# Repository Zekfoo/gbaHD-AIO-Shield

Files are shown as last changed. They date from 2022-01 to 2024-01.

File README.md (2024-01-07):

# gbaHD AIO Shield



This is a Spartan Edge Accelerator shield which implements all the hardware connections needed for zwenergy's [gbaHD](https://github.com/zwenergy/gbaHD), no wires required! The PCB incorporates the GBA motherboard, Arduino Nano, and SNES controller port used in a typical gbaHD installation, and interfaces directly with the Spartan Edge Accelerator board via pin header connections. 



## Disclaimer

Assembly of this PCB requires donor parts from a Game Boy Advance motherboard, and therefore also requires advanced soldering skills. Do not attempt this project unless you are comfortable and confident in your ability to desolder and solder both surface-mount and through-hole components, otherwise you risk irreparable damage to your original console and to this PCB. I claim no responsibility and accept no blame for any failed attempts.

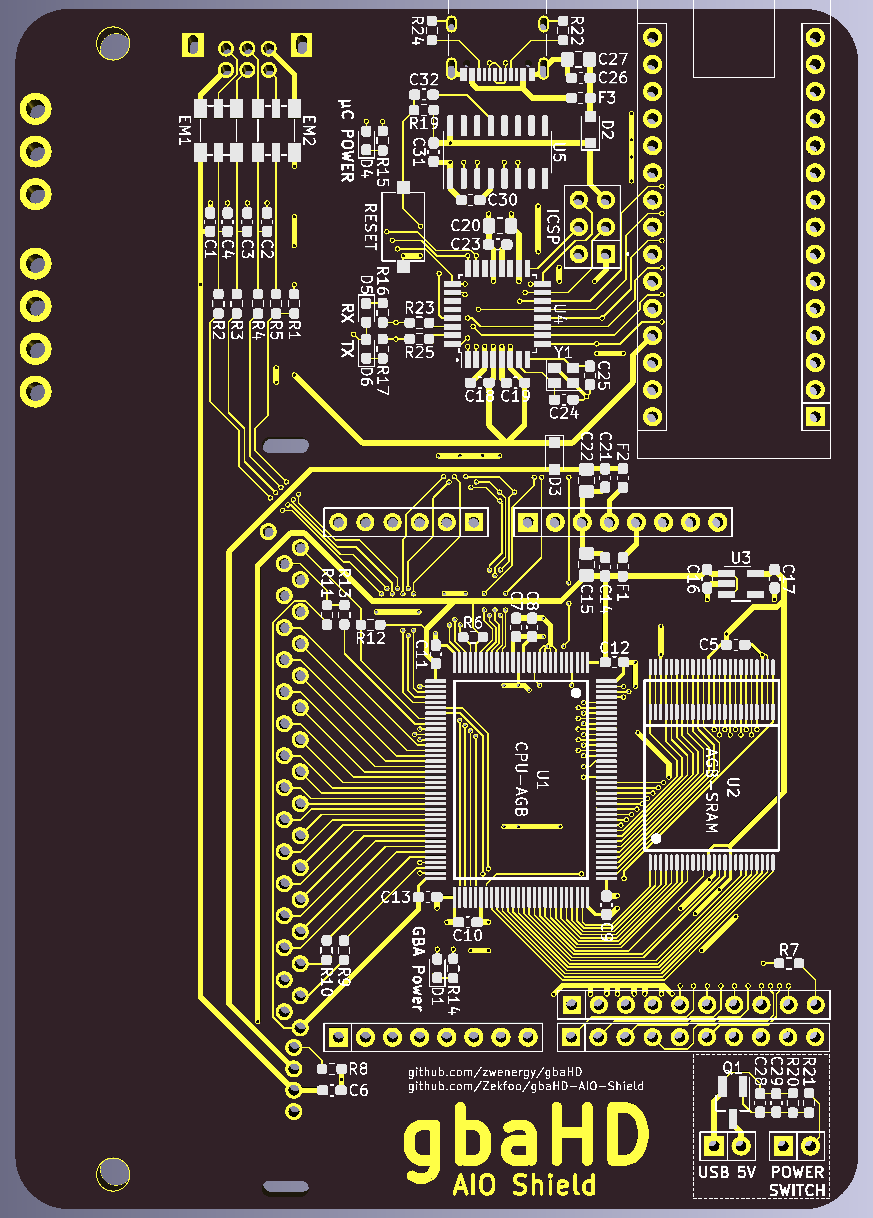
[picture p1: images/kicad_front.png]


## Ordering the board

**READ THE DISCLAIMER SECTION ABOVE BEFORE CONTINUING**

The PCB can be ordered via the following links:

**[PCBWay](https://www.pcbway.com/project/shareproject/gbaHD_AIO_Shield_8eb5e84a.html)** (Full disclosure - this link gives me a small commission from each order - if you're new to PCBWay, feel free to use my [referral link](https://www.pcbway.com/setinvite.aspx?inviteid=422136) to sign up and get $5 off your order)

**[OSHPark](https://oshpark.com/shared_projects/6wbIivMl)**

Or feel free to order from your preferred PCB fab using the gerbers on this repo.

Board thickness of 1.2mm or thinner is recommended. 1.6mm will work, but soldering of some of the through-hole components may be more difficult.

## Bill of materials

There are a couple *optional* features on this PCB to keep in mind before ordering your parts:

**Choice between an onboard ATmega328P or an external Arduino Nano**

The onboard Arduino offers a cleaner look for the assembled PCB, but since ATmega chips are becoming prohibitively expensive during this  chip shortage, there is also support for plugging in your own Arduino Nano via pin headers. *These options are mutually-exclusive, pick one.*

**Master power switch**

This may be useful for consolizer-style installations that use an enclosure, such that a toggle switch can be mounted to the case to switch power to the entire assembly while leaving the USB-C power supply plugged in. This is completely optional, since the power can be switched off using the Spartan Edge Accelerator's own switch or by unplugging the power supply.

The BOM below is separated between donor parts, required parts, and parts for optional features. Read carefully since the optional features may require components that are also listed in earlier sections.

Please source your own passive components, only values and footprints are listed for these.

|  | Reference(s) | Count | Description | Part Number | Comments | Purchase Link |
|---|---|---|---|---|---|---|
| **From donor GBA** | U1 | 1 | AGB CPU | - | - | - |
|  | U2 | 1 | AGB SRAM | - | - | - |
|  | P1 | 1 | Link port | - | - | - |
|  | P2 | 1 | Cart connector | - | - | - |
|  | EM1, EM2 | 2 | Common-mode choke | ACM4532-102-3P | - | - |
|  |  |  |  |  |  |  |
| **Required** | C1, C5, C6, C7, C8, C9, C10, C11, C12, C13, C14, C16, C17, C21 | 14 | 0.1uF 0603 | - | - | - |
|  | C2, C3, C4 | 3 | 100pF 0603 | - | - | - |
|  | C15, C22 | 2 | 10uF 0805 | - | - | - |
|  | D1, D4 | 2 | Green LED 0603 | LTST-C191KGKT | Or generic | https://lcsc.com/product-detail/Light-Emitting-Diodes-LED_Lite-On-LTST-C191KGKT_C125098.html |
|  | D3 | 1 | Schottky diode | B5817WS | - | https://lcsc.com/product-detail/Schottky-Barrier-Diodes-SBD_Yangzhou-Yangjie-Elec-Tech-B5817WS_C699102.html |
|  | F1, F2 | 2 | 1.25A fuse 0603 | - | - | - |
|  | P3 | 1 | SNES controller port | - | - | https://aliexpress.com/item/32828768824.html |
|  | R1, R6, R8, R12 | 4 | 100kOhm 0603 | - | - | - |
|  | R2, R3, R4, R5 | 4 | 330Ohm 0603 | - | - | - |
|  | R7 | 1 | 270Ohm 0603 | - | - | - |
|  | R9, R10 | 2 | 47Ohm 0603 | - | - | - |
|  | R11 | 1 | 18kOhm 0603 | - | - | - |
|  | R13 | 1 | 15Ohm 0603 | - | - | - |
|  | R14 | 1 | 1kOhm 0603 | - | - | - |
|  | U3 | 1 | 2.5V linear regulator | TLV71325PDBV | - | https://lcsc.com/product-detail/Linear-Voltage-Regulators-LDO_Texas-Instruments-TLV71325PDBVR_C90841.html |
|  | S1 | 1 | Spartan Edge Accelerator | - | - | - |
|  | - | 2 | 10-pin male header |  | Or generic, cut to size | https://lcsc.com/product-detail/Pin-Headers_XKB-Connectivity-X6511WV-10H-C30D60_C706882.html |
|  | - | 2 | 8-pin male header |  | Or generic, cut to size | https://lcsc.com/product-detail/Pin-Headers_XKB-Connectivity-X6511WV-08H-C30D60_C706880.html |
|  | - | 1 | 6-pin male header |  | Or generic, cut to size | https://lcsc.com/product-detail/Pin-Headers_XKB-Connectivity-X6511WV-06H-C30D60_C706878.html |
|  | - | 2 | 10-pin female header |  | Or generic, cut to size | https://lcsc.com/product-detail/Female-Headers_XKB-Connectivity-X6511FV-10-C85D32_C718235.html |
|  | - | 2 | 8-pin female header |  | Or generic, cut to size | https://lcsc.com/product-detail/Female-Headers_XKB-Connectivity-X6511FV-08-C85D32_C718237.html |
|  | - | 1 | 6-pin female header |  | Or generic, cut to size | https://lcsc.com/product-detail/Female-Headers_XKB-Connectivity-X6511FV-06-C85D32_C718239.html |
|  |  |  |  |  |  |  |
| **Onboard Arduino Only** | C26 | 1 | 0.1uF 0603 | - | Total 15 pieces including "Required" count | - |
|  | C18, C19 | 2 | 1uF 0603 | - | - | - |
|  | C20, C27 | 2 | 10uF 0805 | - | Total 4 pieces including "Required" count | - |
|  | C23, C30, C31, C32 | 4 | 0.1uF 0603 | - | Total 19 pieces including "Required" count | - |
|  | C24, C25 | 2 | 18pF 0603 | - | - | - |
|  | D2 | 1 | Schottky diode | B5817WS | Total 2 pieces including "Required" count | https://lcsc.com/product-detail/Schottky-Barrier-Diodes-SBD_Yangzhou-Yangjie-Elec-Tech-B5817WS_C699102.html |
|  | D5 | 1 | Red LED 0603 | LTST-C191KRKT | Or generic | https://lcsc.com/product-detail/Light-Emitting-Diodes-LED_Lite-On-LTST-C191KRKT_C125099.html |
|  | D6 | 1 | Green LED 0603 | LTST-C191KGKT | Or generic, total 3 pieces including "Required" count | https://lcsc.com/product-detail/Light-Emitting-Diodes-LED_Lite-On-LTST-C191KGKT_C125098.html |
|  | F3 | 1 | 1.25A fuse 0603 | - | Total 3 pieces including "Required" count | - |
|  | P4 | 1 | USB-C Port | U262-161N-4BVC11 | - | https://lcsc.com/product-detail/USB-Connectors_XKB-Connectivity-U262-161N-4BVC11_C319148.html |
|  | P5 | 1 | 2x3-pin male header | X6521WV-2x03H-C30D60 | Or generic, cut to size | https://lcsc.com/product-detail/Pin-Headers_XKB-Connectivity-X6521WV-2x03H-C30D60_C706893.html |
|  | R15, R16, R17 | 3 | 2.2kOhm 0603 | - | - | - |
|  | R19 | 1 | 100kOhm 0603 | - | Total 5 pieces including "Required" count | - |
|  | R22, R24 | 2 | 5.1kOhm 0603 | - | - | - |
|  | R23, R25 | 2 | 1kOhm 0603 | - | Total 3 pieces including "Required" count | - |
|  | SW1 | 1 | Pushbutton | TS-1101-C-W | - | https://lcsc.com/product-detail/Tactile-Switches_XKB-Connectivity-TS-1101-C-W_C318938.html |
|  | U4 | 1 | Microcontroller | ATmega328P-AU | - | https://lcsc.com/product-detail/ATMEL-AVR_Microchip-Tech-ATMEGA328P-AU_C14877.html |
|  | U5 | 1 | USB-to-serial IC | CH340C | - | https://lcsc.com/product-detail/USB-ICs_WCH-Jiangsu-Qin-Heng-CH340C_C84681.html |
|  | Y1 | 1 | 16MHz crystal | Q24FA20H0023200 | - | https://lcsc.com/product-detail/Crystals_Seiko-Epson-Q24FA20H0023200_C255948.html |
|  |  |  |  |  |  |  |
| **External Arduino Only** | A1 | 1 | Arduino Nano | - | - | - |
|  | - | 2 | 15-pin female header | B-2200S15P-A120 | Or generic, cut to size | https://lcsc.com/product-detail/Female-Headers_Ckmtw-Shenzhen-Cankemeng-B-2200S15P-A120_C124408.html |
|  |  |  |  |  |  |  |
| **Master Power Switch Only** | C28, C29 | 2 | 1uF 0603 | - | Total 4 pieces including "Onboard Arduino" count | - |
|  | Q1 | 1 | P-Channel MOSFET SOT23 | PJM3415PSA | - | https://lcsc.com/product-detail/MOSFETs_PJSEMI-PJM3415PSA_C411717.html |
|  | R20 | 1 | 100kOhm 0603 | - | Total 6 pieces including "Required" count | - |
|  | R21 | 1 | 2.2kOhm 0603 | - | Total 4 pieces including "Onboard Arduino" count | - |
|  | SW2 | 1 | Rocker Switch | RS601HL-1020011BB | Or use any switch of your choice | https://lcsc.com/product-detail/Rocker-Switches_HCTL-RS601HL-1020011BB_C2885783.html |

## Programming the Spartan Edge Accelerator
Refer to zwenergy's [spartan-edge-esp32-boot](https://github.com/zwenergy/spartan-edge-esp32-boot) repo for instructions on how to program the Spartan board's ESP32 (Use 01LoadDefaultBitstream). The ESP32 firmware allows the configuring of the FPGA logic from a bitstream file loaded on the microSD card. 

Save one of the [latest bitstream releases](https://github.com/zwenergy/gbaHD/tree/master/bitstream) as `/overlay/default.bit` on your microSD card.

zwenergy's ESP32 firmware also supports uploading the bitstream file via WiFi, such that the microSD card doesn't need to be removed. Simply connect to the `gbaHD` network hosted by the ESP32 (default password is `gbahdwifi`, this can be modified by editing the ESP32 Arduino sketch), and navigate to http://gbahd.local/ (if this doesn't work, try 192.168.4.1 instead). From here, the web page allows you to upload a bitstream file directly to the microSD card. Bitstream changes are applied after power cycling the Spartan board.

## Programming the Arduino bootloader (onboard Arduino only)

If you assemble this board with an onboard Arduino, the ATmega328p will not come with the Arduino bootloader installed, so it will not be programmable from the Arduino IDE right out of the gate. Follow the [official documentation](https://docs.arduino.cc/built-in-examples/arduino-isp/ArduinoISP) to program the bootloader via the ICSP header on the board (follow the steps to program it as an Arduino Nano, a second Arduino is required).

Note that the onboard Arduino circuit is functionally identical to any Arduino Nano clone that uses a CH340 USB-to-Serial IC. If the microcontroller is not detected as a COM port on your computer, you may need to install the corresponding [driver](https://learn.sparkfun.com/tutorials/how-to-install-ch340-drivers/all).

For advanced users who are familiar with programming microcontrollers via ICSP directly, the CH340C and USB-C port may be omitted entirely.

## Programming the Arduino

The Arduino is used to interface between the SNES controller port and the GBA for button inputs and the reset function. It also interfaces with the Spartan Edge Accelerator for on-screen display controls. Upload this [sketch](https://github.com/Zekfoo/gbaHD-AIO-Shield/blob/main/controller/controller.ino).

By default, the button combos are:
- L+R+X+Y to toggle the OSD
- L+R+START+SELECT to reset the GBA. 
 
These combos can be configured by modifying the `` `define`` macros in the Arduino sketch. 

## Installing the master power switch

As mentioned earlier, this is an optional feature that allows the use of an external toggle switch. This replaces the function of the power switch on the Spartan board itself, which would be inaccessible when installed in an enclosure. The load switch circuit (Q1, C28, C29, R20, R21) allows for the use of any toggle switch, regardless of rated current, and provides debouncing for poor/dirty switch contacts.

1. Switch the power switch on the Spartan board to "EXTVIN-5V"
2. Solder 2 wires from the legs of the power switch labelled "5V" and "USB" on the Spartan board to the corresponding solder points on the shield
3. Solder 2 wires from the master power switch to the solder points labelled "POWER SWITCH" on the shield
4. While the Spartan board is plugged into a USB-C power supply, the master power switch can be used to switch power on and off to the whole assembly

## FAQ

- **Which way should the diodes be installed?**

All the diodes on the board use KiCad built-in diode footprints, though admittedly they might not be the most clear.
The silkscreen labels for the diodes indicate where the cathode is located:

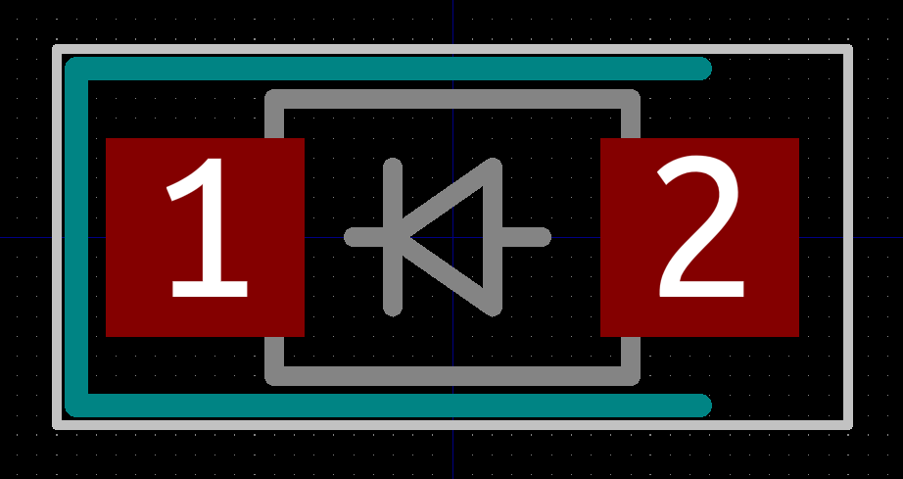
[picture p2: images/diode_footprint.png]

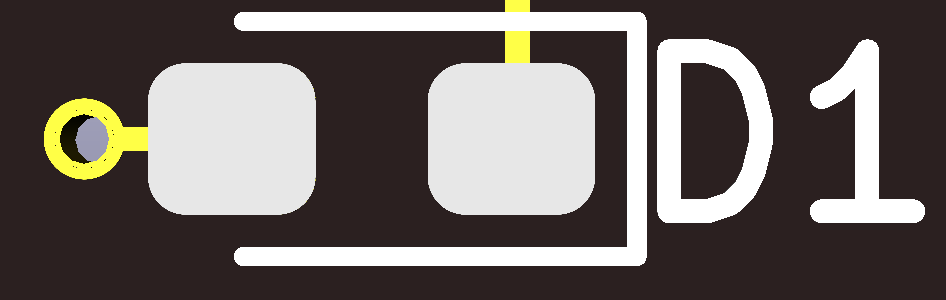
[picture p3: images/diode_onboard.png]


## Known issues

- When using an EZ Flash Omega flash cart, the reset button combo will only reset the loaded ROM. Resetting to the flash cart menu after a ROM has already been loaded requires a manual power reset, or use the flash cart's own reset-to-menu function (L+R+START by default when enabled in the flash cart settings).

## Acknowledgements
As always, thanks to the [Gameboy Discord](https://discord.gg/gameboy) community for their continued support.
Special thanks to [zwenergy](https://github.com/zwenergy) for his hard work on the gbaHD

# License

<br />This work is licensed under a <a rel="license" href="http://creativecommons.org/licenses/by-nc-sa/4.0/">Creative Commons Attribution-NonCommercial-ShareAlike 4.0 International License</a>.

Feel free to modify this design however you like, but please make sure to give credit where it is due. I encourage you to share your improvements with the rest of the Gameboy modding community, I mainly frequent the Gameboy [Discord](https://discord.gg/RYN3bMxr) and [Subreddit](https://www.reddit.com/r/Gameboy/)

Under this license, you are not permitted to profit from or commercialize this design in any part without my express permission.

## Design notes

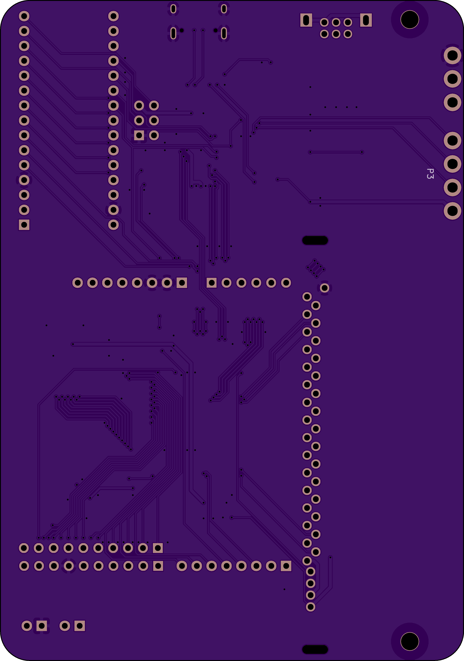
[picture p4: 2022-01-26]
images/osh_back.png

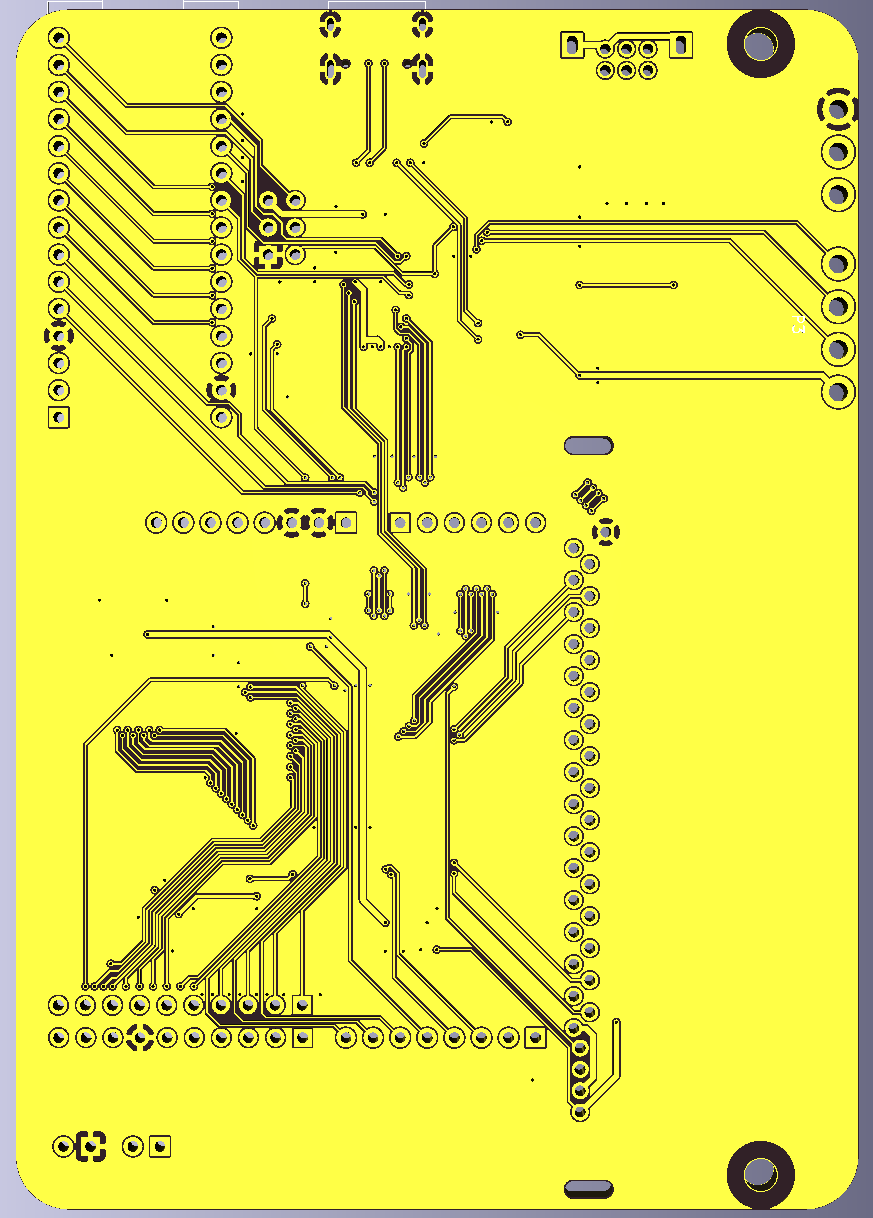
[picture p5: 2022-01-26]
images/kicad_back.png

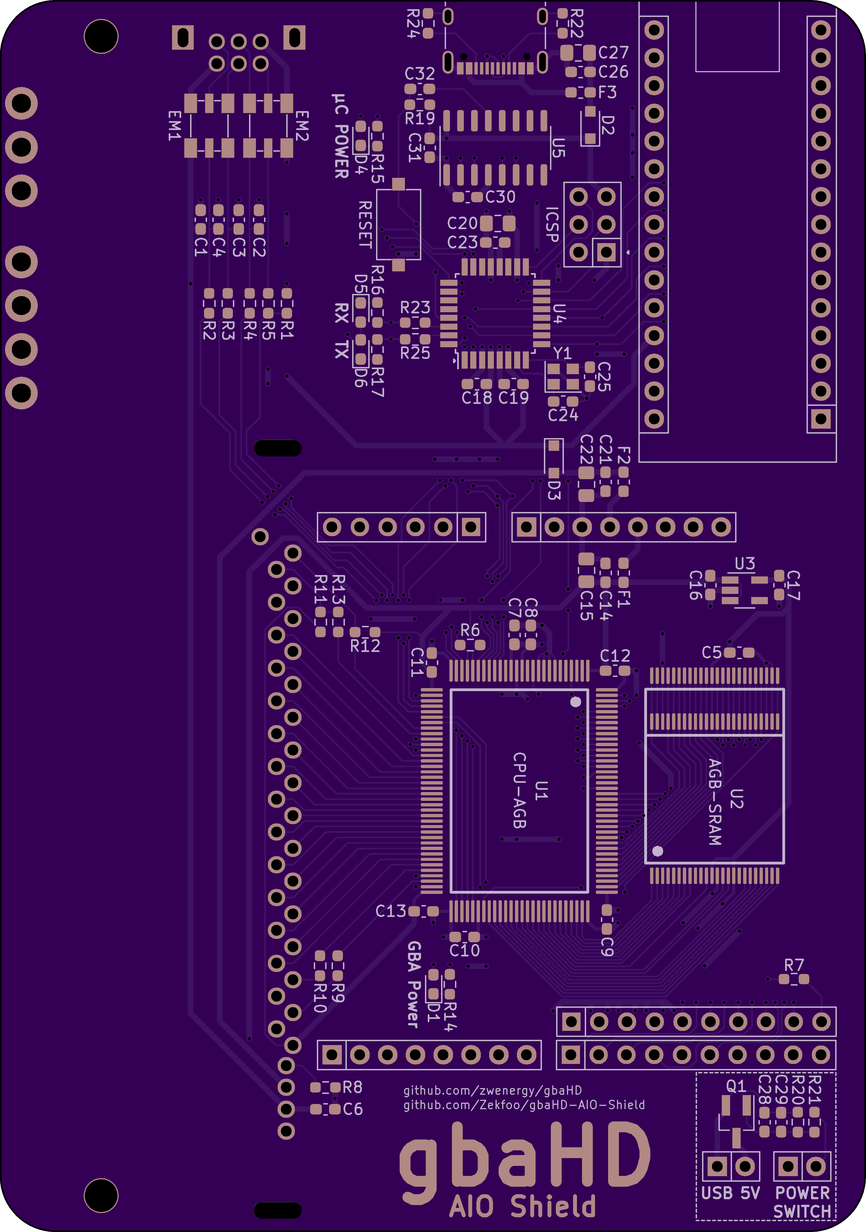
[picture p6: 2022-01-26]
images/osh_front.png

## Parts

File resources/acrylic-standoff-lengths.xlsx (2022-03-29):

Thread | #4-40
Part | Quantity | Notes
Thumb Screw | 4 | For top acrylic mounting
Machine Screw | 2 | For SEA mounting
Nut | 6 | For securing bottom acrylic
Flat Washers | - | May be needed to adjust spacing
3/8in Standoff | 2 | Mounting holes between the SEA and the bottom acrylic
3/4in Standoff | 2 | Front mounting holes between the shield and the bottom acrylic
7/8in Standoff | 2 | Front mounting holes between the top acrylic and the shield
1 5/8in Standoff | 2 | Rear mounting holes between the top and bottom acrylic
Rubber Feet | -

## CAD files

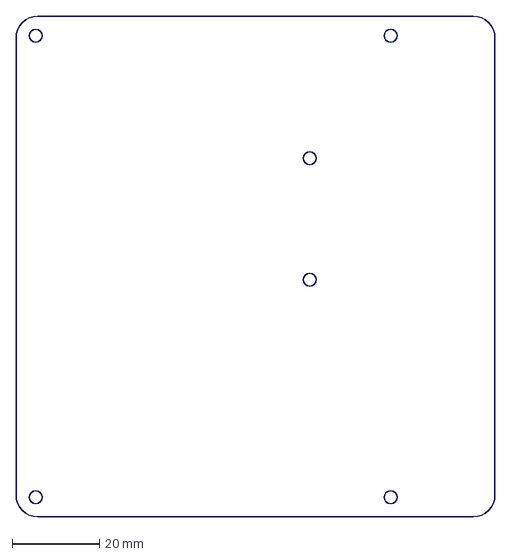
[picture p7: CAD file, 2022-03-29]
resources/acrylic-bottom.DXF
110.0 x 115.0 mm

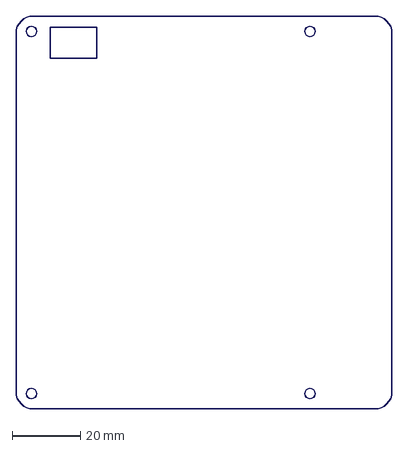
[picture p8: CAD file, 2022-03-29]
resources/acrylic-top.DXF
110.0 x 115.0 mm

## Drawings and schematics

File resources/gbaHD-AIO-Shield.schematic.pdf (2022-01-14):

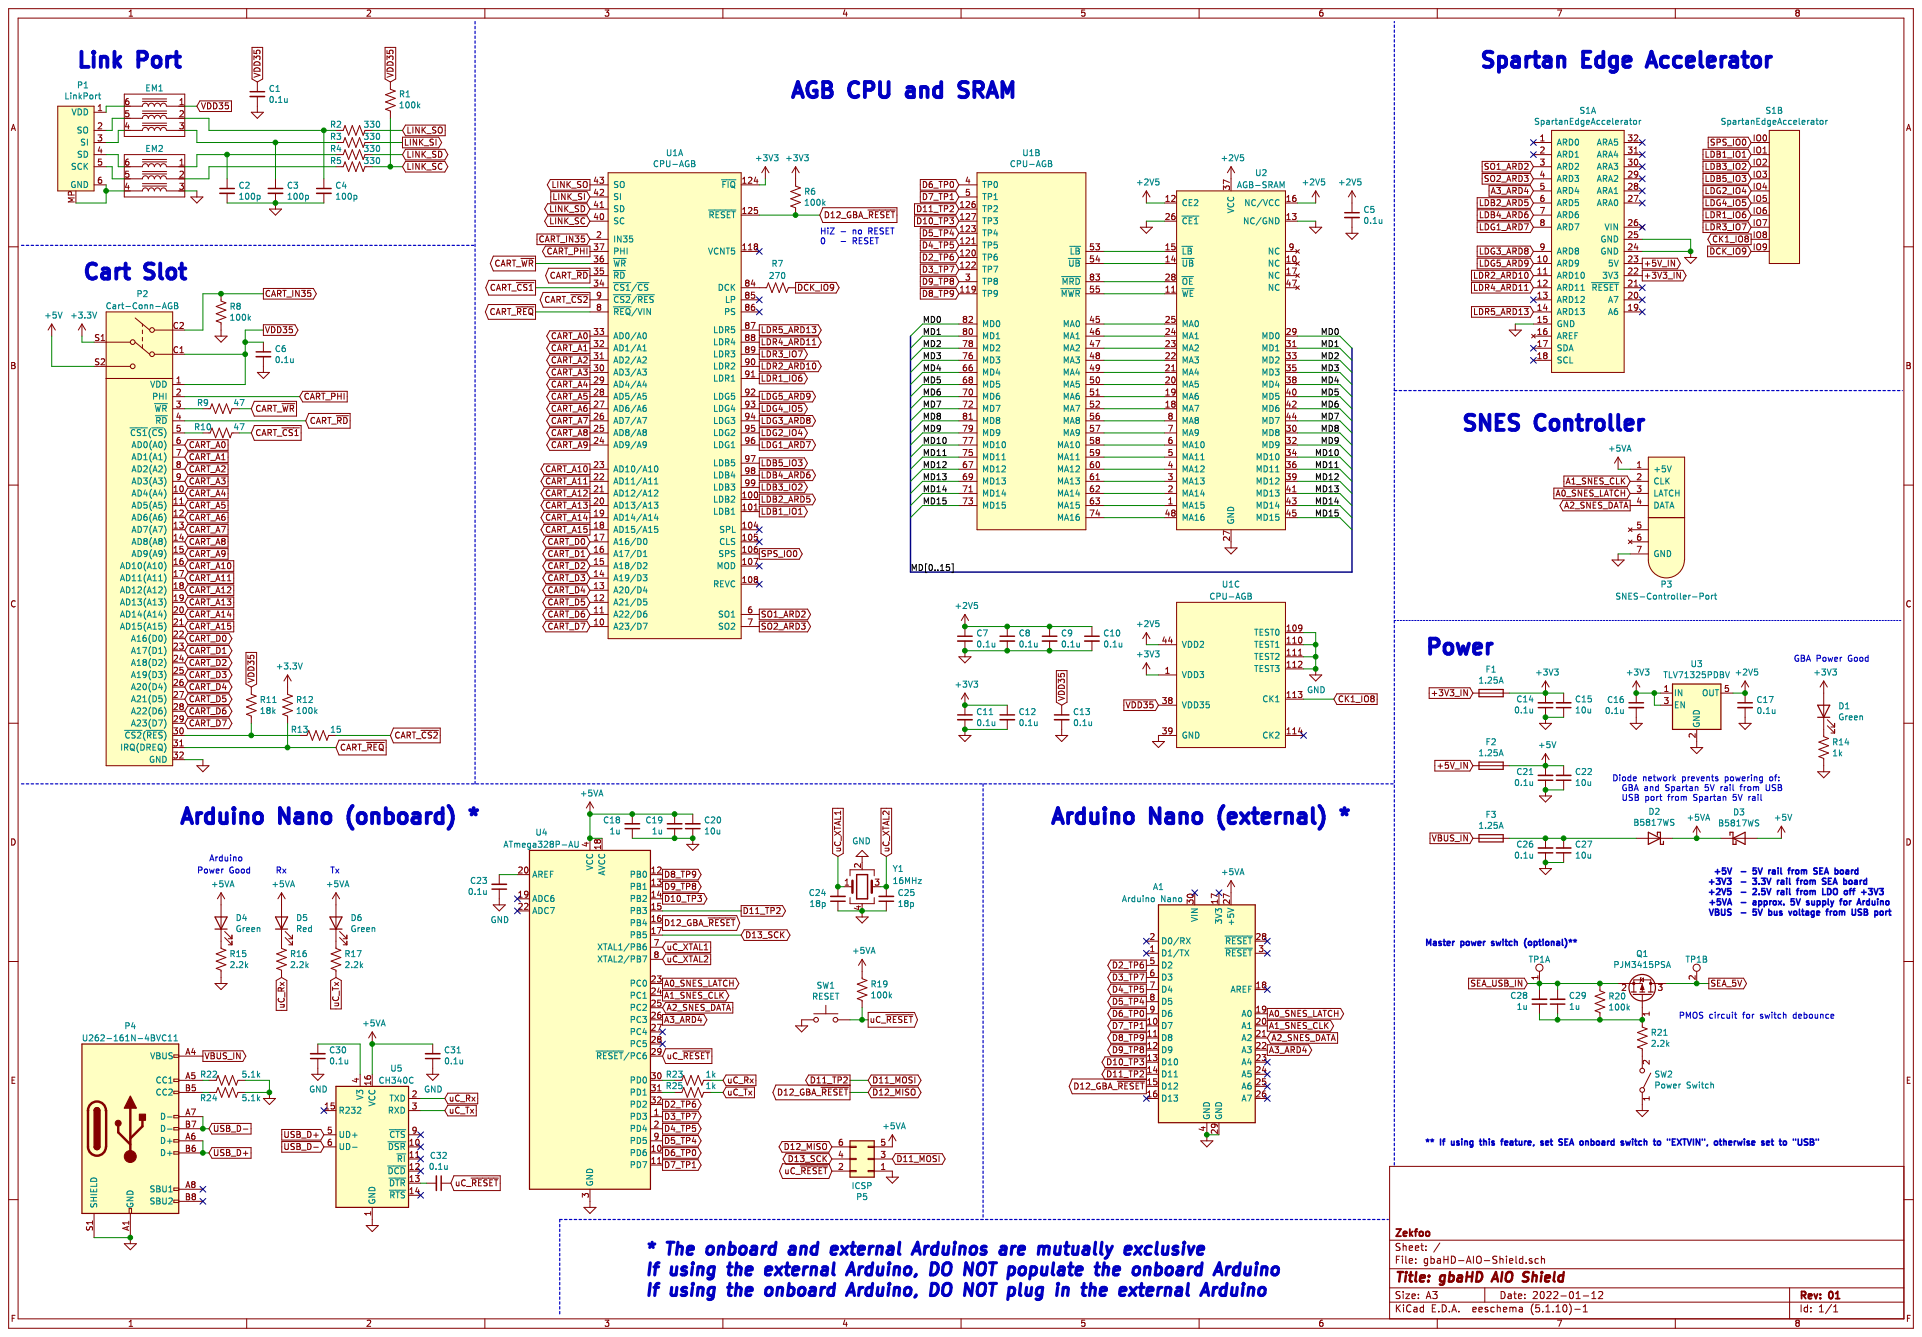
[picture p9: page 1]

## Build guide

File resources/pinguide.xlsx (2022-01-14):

 |  |  | SEA | Arduino | ATmega328p | GBA |  | SNES Controller **
 |  |  |  |  |  | Pin Name | Testpoint Number *
 |  |  | 3V3 |  |  | B+ |  |  | Power
Power |  |  | 5V | 5V | 4,6,18 |  |  | 5V
 |  |  | GND | GND | GND | B- |  | GND | Ground (duh!)
OUTPUT | --> | INPUT | ARD2 |  |  | SO1 |  |  | Audio
 |  |  | ARD3 |  |  | SO2
* |  |  | ARD4 | A3 | 26 |  |  |  | OSD Toggle
 |  |  | ARD5 |  |  | LDB2 | 6 |  | Video
 |  |  | ARD6 |  |  | LDB4 | 8
 |  |  | ARD7 |  |  | LDG1 | 10
 |  |  | ARD8 |  |  | LDG3 | 12
 |  |  | ARD9 |  |  | LDG5 | 14
 |  |  | ARD10 |  |  | LDR2 | 16
 |  |  | ARD11 |  |  | LDR4 | 18
 |  |  | ARD13 |  |  | LDR5 | 19
 |  |  | IO0 |  |  | SPS | 2
 |  |  | IO1 |  |  | LDB1 | 5
 |  |  | IO2 |  |  | LDB3 | 7
 |  |  | IO3 |  |  | LDB5 | 9
 |  |  | IO4 |  |  | LDG2 | 11
 |  |  | IO5 |  |  | LDG4 | 13
 |  |  | IO6 |  |  | LDR1 | 15
 |  |  | IO7 |  |  | LDR3 | 17
 |  |  | IO8 |  |  | CK1 |  |  | GBA Clock
 |  |  | IO9 |  |  | DCK | 22 |  | Video Clock
 |  |  |  | D2 | 32 | TP6 |  |  | GBA Buttons
 |  |  |  | D3 | 1 | TP7
 |  |  |  | D4 | 2 | TP5
 |  |  |  | D5 | 9 | TP4
 |  |  |  | D6 | 10 | TP0
 |  |  |  | D7 | 11 | TP1
 |  |  |  | D8 | 12 | TP9
 |  |  |  | D9 | 13 | TP8
** |  |  |  | D10 | 14 | TP3
 |  |  |  | D11 | 15 | TP2
 |  |  |  | D12 | 16 | RESET |  |  | GBA Reset
 |  |  |  | A0 | 23 |  |  | Latch | SNES Interface
 |  |  |  | A1 | 24 |  |  | Clk
 |  |  |  | A2 | 25 |  |  | Data

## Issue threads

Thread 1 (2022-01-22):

Uploading the SNES Controller Program to the Arduino Nano

matteog, 2022-01-22:
Ok so I just discovered something. I bought an off-brand Nano, and when I tried to upload the SNES controller program to it, I got an error. After a couple of seconds of searching I came across the Processor option under Tools in the Arduino suite.

I selected the Atmega328P (Old Bootloader) option, and then the program got flashed correctly. So I think what is happening is that Arduino defaults to the regular Atmega328P processor bootloader option, which I believe is powering the newer Nano Every.

This was on a Windows PC running version 1.8.18 of the Arduino suite.

Zekfoo, 2022-01-22:
This is a known issue for some Nano clones, but it is not specific to the shield.

Closed 2022-01-22.

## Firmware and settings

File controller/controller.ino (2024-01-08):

/* 
 *  Modified from https://github.com/zwenergy/gbaHD
 *  Some code snippets also borrowed from https://github.com/ManCloud/GBAHD-Shield
 *  Edit GBA_RESET_COMBO and OSD_COMBO to configure the button combos for GBA reset and OSD toggle respectively
*/

#include <EEPROM.h>

//// Pin definitions

// GBA outputs
#define DUP 2
#define DDOWN 3
#define DLEFT 4
#define DRIGHT 5
#define BUTA 6
#define BUTB 7
#define BUTL 8
#define BUTR 9
#define BUTSTART 10
#define BUTSELECT 11
#define GBARESET 12

// SNES controller
#define SNESLATCH A0
#define SNESCLK A1
#define SNESSERIAL A2

// Communication port
#define COMPIN A3

// Polling interval in ms
#define POLLINT 10

// Some NOP definitions.
// Yes, this is very pretty. But we do not have code size problems,
// hence using stupid sequences of NOPs makes it nicely timing 
// predictable.
#define NOP1 asm volatile( "nop\n" )
#define NOP2   NOP1;  NOP1
#define NOP4   NOP2;  NOP2
#define NOP8   NOP4;  NOP4
#define NOP16  NOP8;  NOP8
#define NOP32  NOP16; NOP16;
#define NOP64  NOP32; NOP32;
#define NOP128 NOP64; NOP64;

#define WAIT4US  NOP64
#define WAIT10US NOP128; NOP32;
#define WAIT14US NOP128; NOP64; NOP32;


// OSD config struct
typedef struct config_tag {
  uint8_t smoothing :2;
  uint8_t pixelGrid :2;
  uint8_t multGrid :1;
  uint8_t color :1;
  uint8_t freq :1;
  uint8_t padDisp :1;
} config_t;

// Pad display offsets
#define PAD_DISP_A      (0x010)
#define PAD_DISP_B      (0x020)
#define PAD_DISP_UP     (0x001)
#define PAD_DISP_DOWN   (0x002)
#define PAD_DISP_LEFT   (0x004)
#define PAD_DISP_RIGHT  (0x008)
#define PAD_DISP_L      (0x040)
#define PAD_DISP_R      (0x080)
#define PAD_DISP_START  (0x100)
#define PAD_DISP_SELECT (0x200)
#define PAD_DISP_MASK   (0x3FF)

// Controller state offsets
#define CON_UP     (0x001)
#define CON_DOWN   (0x002)
#define CON_LEFT   (0x004)
#define CON_RIGHT  (0x008)
#define CON_A      (0x010)
#define CON_B      (0x020)
#define CON_L      (0x040)
#define CON_R      (0x080)
#define CON_START  (0x100)
#define CON_SELECT (0x200)
#define CON_X      (0x400)
#define CON_Y      (0x800)
#define CON_MASK   (0xFFF)

// Button combo macros
#define GBA_RESET_COMBO (CON_L | CON_R | CON_SELECT | CON_START)
#define OSD_COMBO       (CON_L | CON_R | CON_X | CON_Y)

uint16_t controllerState, lastState; // b000000, Select, Start, R, L, B, A, Right, Left, Down, Up}

uint8_t gbaReset;

uint8_t gotCombo;

uint8_t showOSD;

// Read the controller
void readController() {
  controllerState = 0;
  // Set the latch to high for 12 us.
  digitalWrite( SNESLATCH, 1 );
  delayMicroseconds( 12 );
  digitalWrite( SNESLATCH, 0 );
  delayMicroseconds( 6 );

  // Shift in the controller data.
  for ( uint8_t i = 0; i < 16; ++i ) {
    digitalWrite( SNESCLK, 0 );
    delayMicroseconds( 6 );
    // We only care about the first 12 bits.
    if ( i < 12 ) {
      uint8_t curDat = !digitalRead( SNESSERIAL );
      if (curDat) {
        switch ( i ) {
          case 0:
            controllerState |= CON_B;
            break;
          case 1:
            controllerState |= CON_Y;
            break;
          case 2:
            controllerState |= CON_SELECT;
            break;
          case 3:
            controllerState |= CON_START;
            break;
          case 4:
            controllerState |= CON_UP;
            break;
          case 5:
            controllerState |= CON_DOWN;
            break;
          case 6:
            controllerState |= CON_LEFT;
            break;
          case 7:
            controllerState |= CON_RIGHT;
            break;
          case 8:
            controllerState |= CON_A;
            break;
          case 9:
            controllerState |= CON_X;
            break;
          case 10:
            controllerState |= CON_L;
            break;
          case 11:
            controllerState |= CON_R;
            break;
          default:
            break;
        }
      }
    }
    digitalWrite( SNESCLK, 1 );
    delayMicroseconds( 6 );
  }
}

// Drive GBA signals
void updateGBASignals() {
  // In case a button is pressed, we pull the signal to ground.
  // Otherwise, we set it to high Z.
  // Since all output registers are already set to 0, we only need
  // to toggle the port direction.
  // Get D0 and D1 directions.
  uint8_t dir = DDRD & 0b00000011;
  if (controllerState & CON_UP)    dir |= 1 << 2;
  if (controllerState & CON_DOWN)  dir |= 1 << 3;
  if (controllerState & CON_LEFT)  dir |= 1 << 4;
  if (controllerState & CON_RIGHT) dir |= 1 << 5;
  if (controllerState & CON_A)     dir |= 1 << 6;
  if (controllerState & CON_B)     dir |= 1 << 7;
  // Write them.
  DDRD = dir;

  // The next ones.
  dir = 0;
  if (controllerState & CON_L)      dir |= 1;
  if (controllerState & CON_R)      dir |= 1 << 1;
  if (controllerState & CON_START)  dir |= 1 << 2;
  if (controllerState & CON_SELECT) dir |= 1 << 3;
  // Write them.
  DDRB = dir; 
}

void rebootGBA(bool hold) {
  DDRB = 1 << 4;
  if (!hold) {
    delay(10);
    DDRB = 0;
  }
}

config_t config_byte = {0,0,0,0,0,0};
config_t config_byte_bak = {0,0,0,0,0,0};

void osdWriteConfig(void) {
    sendPacket(0x4000 | *((uint8_t*)(&config_byte)));
}

void osdInit(void){
    uint8_t tmpVal = EEPROM.read((uint8_t *)(E2END-1));
    if(tmpVal == 0xFF) tmpVal = 0;
    config_byte = *((config_t *)(&tmpVal));
    osdWriteConfig();
}

void osdEnter(void) {
    config_byte_bak = config_byte;
    if(config_byte.padDisp) {
        delay(10);
        sendPacket( (0x8000));
        delay(10);
        sendPacket( (0x8000));
        delay(10);
    }
}


#define OSD_MIN_IDX 3
#define OSD_MAX_IDX 8
bool osdUpdate() {
    bool retVal = true;

    static uint8_t osd_idx = OSD_MIN_IDX;
    static uint16_t last_buttons = 0;

    if(controllerState != last_buttons) {
        last_buttons = controllerState;
        if(controllerState) {
            bool updateOSD = true;
            switch(controllerState) {
                case CON_UP: {
                    osd_idx = ((osd_idx > OSD_MIN_IDX) ? (osd_idx - 1) : OSD_MIN_IDX);
                } break;
                case CON_DOWN: {
                    osd_idx = ((osd_idx < OSD_MAX_IDX) ? (osd_idx + 1) : OSD_MAX_IDX);
                } break;
                case CON_A: {
                    updateOSD = false;
                    switch (osd_idx){
                        case 3: config_byte.pixelGrid = ( (config_byte.pixelGrid < 3) ? ((config_byte.pixelGrid << 1) + 1) : 0); break;
                        case 4: config_byte.multGrid = !config_byte.multGrid; break;
                        case 5: config_byte.smoothing = ( (config_byte.smoothing < 2) ? (config_byte.smoothing + 1) : 0); break;
                        case 6: config_byte.color = !config_byte.color; break;
                        case 7: config_byte.freq = !config_byte.freq; break;
                        case 8: config_byte.padDisp = !config_byte.padDisp; break;
                    }
                    osdWriteConfig();
                } break;
                case CON_B: {
                    config_byte = config_byte_bak;
                    osdWriteConfig();
                    retVal = false;
                    osd_idx = OSD_MIN_IDX;
                } break;
                case CON_START: {
                    EEPROM.update((uint8_t *)(E2END-1), *(uint8_t *)(&config_byte));
                    retVal = false;
                    osd_idx = OSD_MIN_IDX;
                } break;
            }
            if(updateOSD) {
                delay(10);
                sendPacket( (0x2000) | (osd_idx << 1) | (retVal ? 1 : 0) );
                delay(10);
                sendPacket( (0x2000) | (osd_idx << 1) | (retVal ? 1 : 0) );
                delay(10);
            }
        }
    }
    return retVal;
}

void padUpdate() {
    uint16_t pad_display_word = 0x8000;
    if (controllerState & CON_A)      pad_display_word |= PAD_DISP_A;
    if (controllerState & CON_B)      pad_display_word |= PAD_DISP_B;
    if (controllerState & CON_UP)     pad_display_word |= PAD_DISP_UP;
    if (controllerState & CON_DOWN)   pad_display_word |= PAD_DISP_DOWN;
    if (controllerState & CON_LEFT)   pad_display_word |= PAD_DISP_LEFT;
    if (controllerState & CON_RIGHT)  pad_display_word |= PAD_DISP_RIGHT;
    if (controllerState & CON_L)      pad_display_word |= PAD_DISP_L;
    if (controllerState & CON_R)      pad_display_word |= PAD_DISP_R;
    if (controllerState & CON_START)  pad_display_word |= PAD_DISP_START;
    if (controllerState & CON_SELECT) pad_display_word |= PAD_DISP_SELECT;
    sendPacket(pad_display_word);
}


// Send packet to FPGA
void sendPacket( uint16_t p ) {
  for ( uint16_t i = 1; i != 0; i<<=1 ) {
    if (p & i) {
      PORTC &= B11110111;
      WAIT4US;
      PORTC |= B00001000;
      WAIT10US;
    } else {
      PORTC &= B11110111;
      WAIT14US;
      PORTC |= B00001000;
    }
  }
}

// Clear the button states
void noButtons() {
  controllerState = 0;
}

// For serial debug only
void debugOutput() {
  Serial.print("DEBUG: ");
  Serial.print(controllerState, BIN);
  Serial.print(" ");
  if(controllerState & CON_A)      Serial.print("A ");
  if(controllerState & CON_B)      Serial.print("B ");
  if(controllerState & CON_X)      Serial.print("X ");
  if(controllerState & CON_Y)      Serial.print("Y ");
  if(controllerState & CON_L)      Serial.print("L ");
  if(controllerState & CON_R)      Serial.print("R ");
  if(controllerState & CON_START)  Serial.print("START ");
  if(controllerState & CON_SELECT) Serial.print("SELECT ");
  if(controllerState & CON_UP)     Serial.print("UP ");
  if(controllerState & CON_DOWN)   Serial.print("DOWN ");
  if(controllerState & CON_LEFT)   Serial.print("LEFT ");
  if(controllerState & CON_RIGHT)  Serial.print("RIGHT ");
  if(gbaReset) Serial.print("RESET ");
  Serial.println();
}

void setup() {
  // DEBUG.
  Serial.begin(115200);
  Serial.println( "Startup" );
  
  // Set up pin modes.

  // Hold GBA reset low
  pinMode( GBARESET, OUTPUT );
  digitalWrite( GBARESET, 0 );
  
  // First set all output registers of GBA buttons to 0.
  pinMode( DUP, OUTPUT );
  digitalWrite( DUP, 0 );
  pinMode( DDOWN, OUTPUT );
  digitalWrite( DDOWN, 0 );
  pinMode( DLEFT, OUTPUT );
  digitalWrite( DLEFT, 0 );
  pinMode( DRIGHT, OUTPUT );
  digitalWrite( DRIGHT, 0 );
  pinMode( BUTA, OUTPUT );
  digitalWrite( BUTA, 0 );
  pinMode( BUTB, OUTPUT );
  digitalWrite( BUTB, 0 );
  pinMode( BUTL, OUTPUT );
  digitalWrite( BUTL, 0 );
  pinMode( BUTR, OUTPUT );
  digitalWrite( BUTR, 0 );
  pinMode( BUTSTART, OUTPUT );
  digitalWrite( BUTSTART, 0 );
  pinMode( BUTSELECT, OUTPUT );
  digitalWrite( BUTSELECT, 0 );

  // Then GBA pins are set to input to hold
  // them as high Z.
  pinMode( DUP, INPUT );
  pinMode( DLEFT, INPUT );
  pinMode( DRIGHT, INPUT );
  pinMode( DDOWN, INPUT );
  pinMode( BUTA, INPUT );
  pinMode( BUTB, INPUT );
  pinMode( BUTL, INPUT );
  pinMode( BUTR, INPUT );
  pinMode( BUTSTART, INPUT );
  pinMode( BUTSELECT, INPUT );
  // Release GBA reset
  pinMode( GBARESET, INPUT );

  // And the SNES controller pins.
  pinMode( SNESLATCH, OUTPUT );
  digitalWrite( SNESLATCH, 0 );
  pinMode( SNESCLK, OUTPUT );
  digitalWrite( SNESCLK, 1 );
  pinMode( SNESSERIAL, INPUT_PULLUP );

  // Communication pin.
  pinMode( COMPIN, OUTPUT );
  digitalWrite( COMPIN, 1 );

  rebootGBA(true);
  delay(5000); // Placeholder delay to wait for FPGA to be programmed
  osdInit();
  rebootGBA(false);
}

void loop() {
  readController();

  if (lastState != controllerState) {
      lastState = controllerState;
      switch (controllerState)
      {
          case GBA_RESET_COMBO: {
              rebootGBA(false);
          } break;
          case OSD_COMBO: {
              osdEnter();
              showOSD = true;
          } break;
      }
  }
  
  if (showOSD) {
      showOSD = osdUpdate();
      noButtons();    //clear controller data as long as OSD is enabled
  } else if(config_byte.padDisp) {
      padUpdate();
  }

  // Only update GBA signals if the menu is not active.
  if ( !showOSD ) {
    //debugOutput();
    updateGBASignals();
  }
}

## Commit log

2022-01-14 Gerbers and other files
    [gbaHD-AIO-Shield-B_Cu.gbr, gbaHD-AIO-Shield-B_Mask.gbr, gbaHD-AIO-Shield-B_Paste.gbr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]
2022-01-14 Update BOM
    [gbaHD-AIO-Shield.bom.xlsx]
2022-01-23 Clarified onboard Arduino and master power switch
2022-01-23 Clarified Spartan board programming
2022-01-26 Fixed BOM errors, adjusted silkscreen labels
    [gbaHD-AIO-Shield-B_Cu.gbr, gbaHD-AIO-Shield-B_Mask.gbr, gbaHD-AIO-Shield-B_Paste.gbr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]
2022-01-26 Fix BOM errors in README
2022-01-26 Fix BOM errors in spreadsheet
    [gbaHD-AIO-Shield.bom.xlsx]
2022-01-26 Updated images to reflect new updated silkscreen
2022-02-03 Fixed BOM error
    [gbaHD-AIO-Shield.bom.xlsx]
2022-02-03 Added images of diode footprint
2022-02-03 Added FAQ section - diode orientation
2022-03-29 Added resources for acrylic standoff enclosure
    [acrylic-bottom.DXF, acrylic-standoff-lengths.xlsx, acrylic-top.DXF]
2024-01-08 Quick hack to make Arduino sketch compatible with latest bitstream (v1.4a)
